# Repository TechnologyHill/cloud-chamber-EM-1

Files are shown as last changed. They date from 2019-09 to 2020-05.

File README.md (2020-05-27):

# Cloud Chamber EM-1

[more about cloud chamber](https://en.wikipedia.org/wiki/Cloud_chamber)

#### Our goal is make a small cloud chamber based on thermoelectric cooling.
#### viewport size is 100 mm x 200 mm.

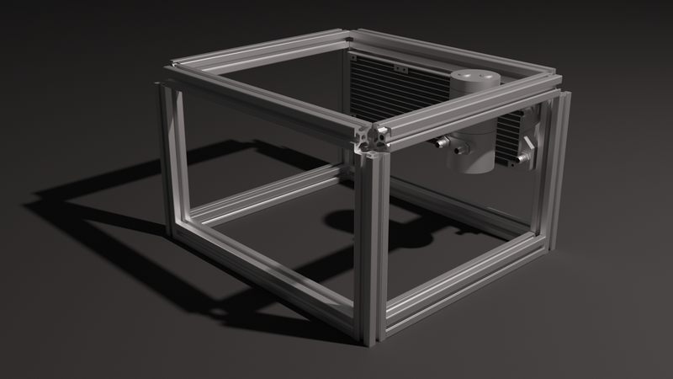
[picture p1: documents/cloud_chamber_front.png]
Cloud Chamber visualization (front)

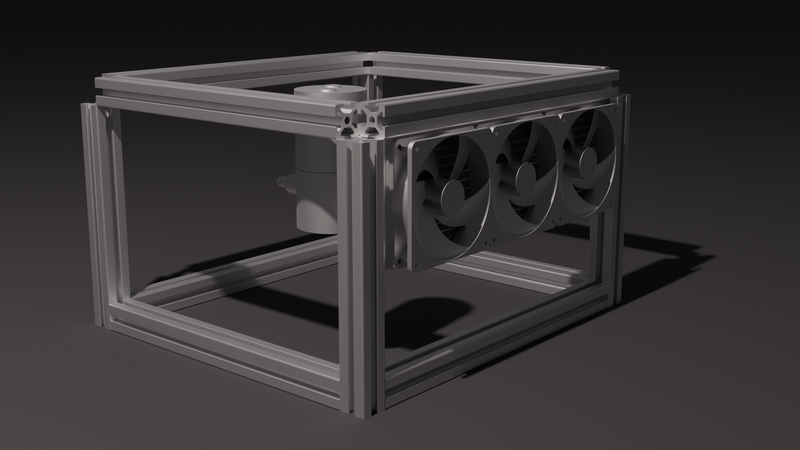
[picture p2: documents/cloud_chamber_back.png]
Cloud Chamber visualization (back)


## Cooling system
Cooling system

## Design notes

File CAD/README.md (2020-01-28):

# 3D printed models

We create 3D models in [OpenSCAD](https://www.openscad.org).

To render *.stl* files by [makefile](https://github.com/ExperimentalMakers/cloud-chamber-EM-1/blob/master/CAD/Makefile) you must install *stlsort*

```sudo pip install stlsort```

```make```

# Filename system

**1**001_P_bk.scad =>
The first digit means section of cloud chamber (casing)

1**0**01_P_bk.scad =>
The second digit means type of model (0 for *single part* or 1 for *assembly model*)

10**10**_P_bk.scad =>
The third digits means number of model

1001_**P**_bk.scad =>
The first letter means type of material (P - *PLA*, A - *ABS*, G - *PET-G*, Al, Cu, Fe)

1001_P_**bk**.scad =>
The second letters means color of material (black, white, etc.)

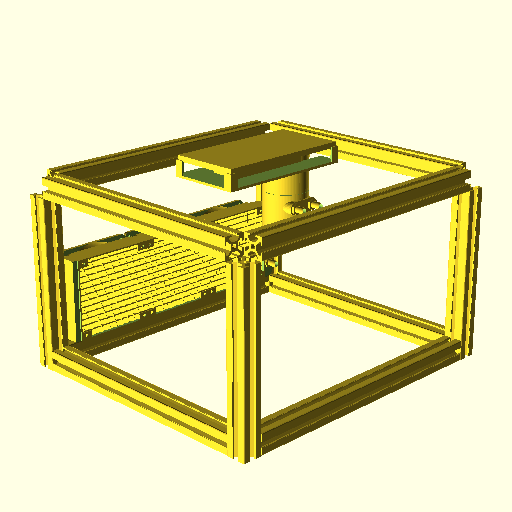
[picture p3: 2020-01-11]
CAD/images/cloud_chamber.png

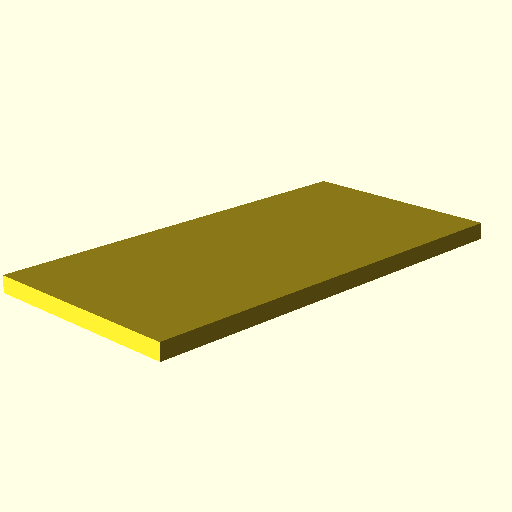
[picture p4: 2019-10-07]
CAD/images/1002_Cu.png

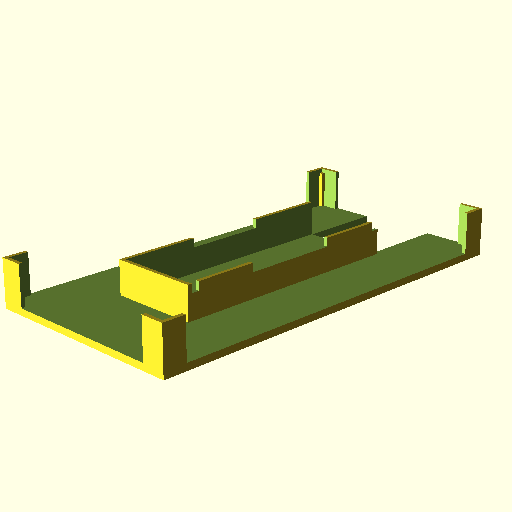
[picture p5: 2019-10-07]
CAD/images/1001_P_bk.png

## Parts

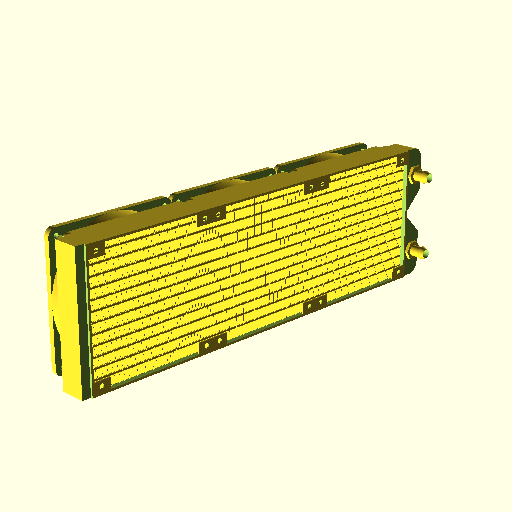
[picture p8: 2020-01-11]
CAD/images/components/fan_radiator.png

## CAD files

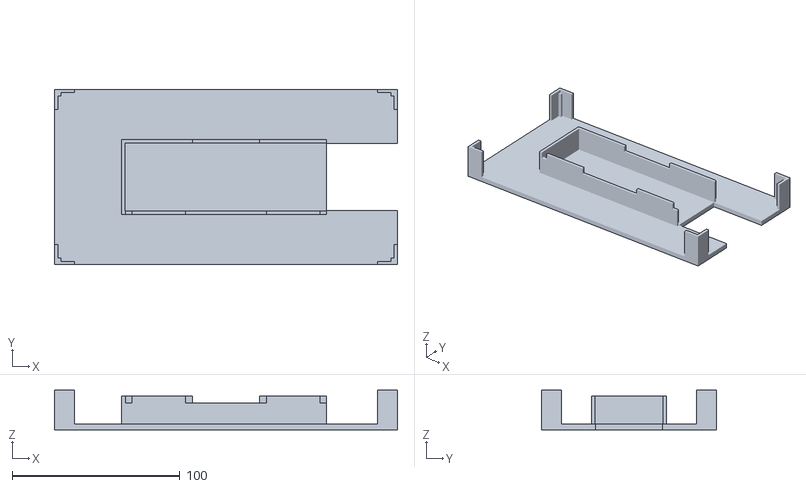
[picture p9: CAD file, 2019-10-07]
CAD/STL/1001_P_bk.stl
204.5 x 104.5 x 23.8

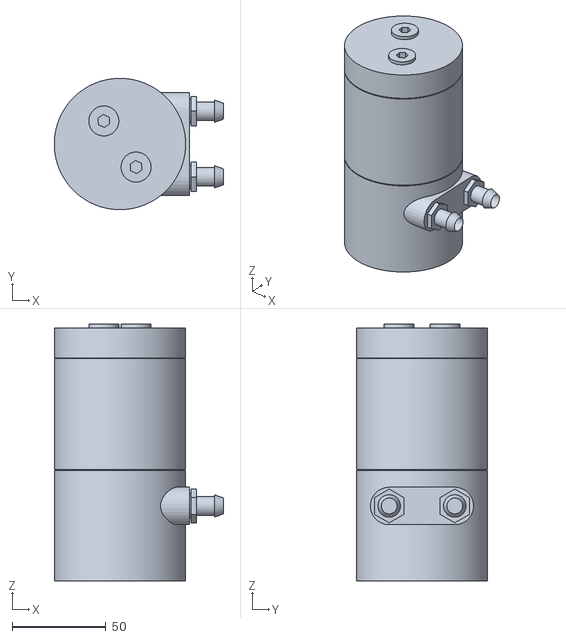
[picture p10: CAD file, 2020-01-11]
CAD/STL/components/pump.stl
90.3 x 70.0 x 137.0

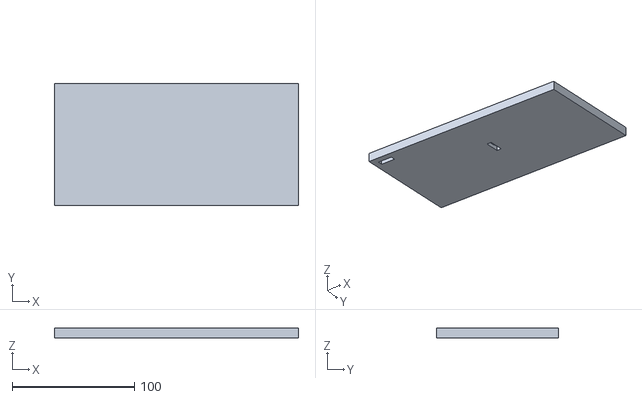
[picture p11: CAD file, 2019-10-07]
CAD/STL/1002_Cu.stl
200.0 x 100.0 x 8.00

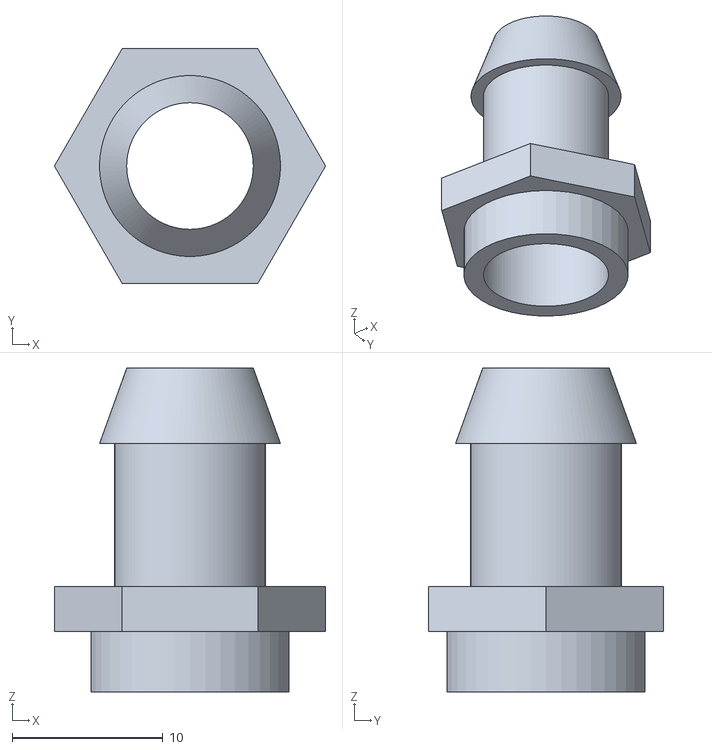
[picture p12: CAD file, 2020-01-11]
CAD/STL/components/fitting.stl
18.0 x 15.6 x 21.5

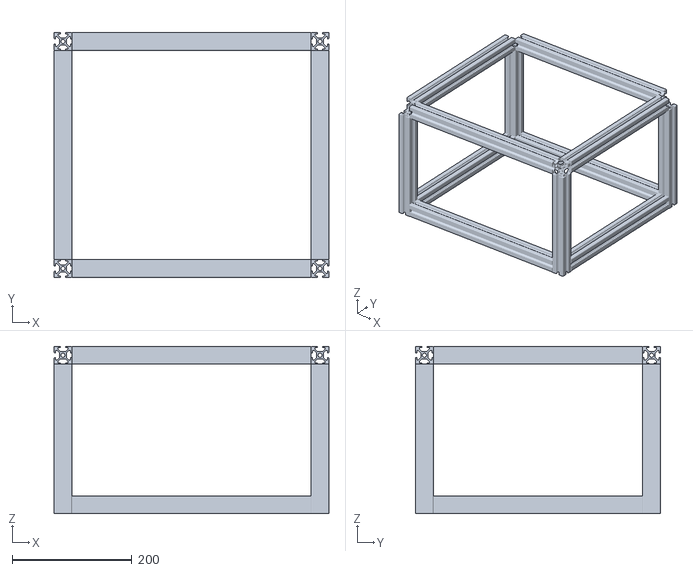
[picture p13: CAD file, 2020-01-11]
CAD/STL/components/frame.stl
460.0 x 410.0 x 280.0

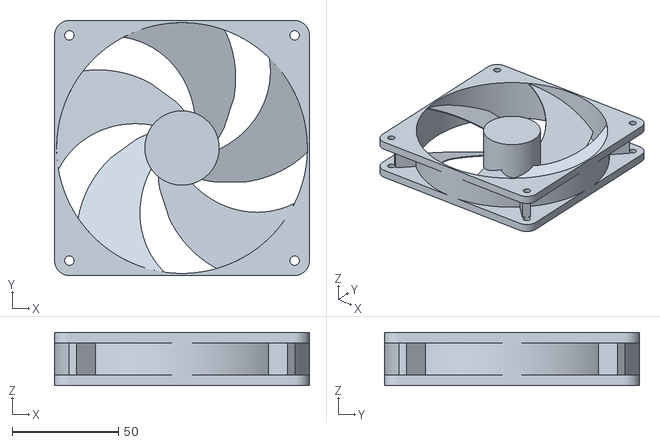
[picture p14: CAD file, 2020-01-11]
CAD/STL/components/fan.stl
120.0 x 120.0 x 25.1

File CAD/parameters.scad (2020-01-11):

//|==========================================|//
//|               CLOUD CHAMBER              |//
//|==========================================|//


//========== FUNCTIONS ==========//

//unit conversions
function inch_to_mm(inch) = inch*25.4;
function mm_to_inch(mm) = mm/25.4;


//========== SCREWS ==========//

//Screw diameter and nut for M10 [mm]
M10_screw_diameter=10.4;
M10_head_height = 10;
M10_head_diameter = 16+0.5;
M10_nut_height = 10.5;
M10_nut_diameter = 25.5;
M10_nut_pocket = 22.3;

//Screw diameter and nut for M8 [mm]
M8_screw_diameter = 8 + 1;
M8_head_height = 8;
M8_head_diameter = 13.5;
M8_nut_height = 7.5;
M8_nut_diameter = 14.4 + 0.5;
M8_nut_pocket = 13 + 0.5;

//Screw diameter and nut for M6 [mm]
M6_screw_diameter=6.5;
M6_head_diameter = 10+0.5;
M6_head_height = 6;
M6_nut_height = 4.9;
M6_nut_diameter = 11.8;
M6_nut_pocket = 10.4;

//Screw diameter and nut for M5 [mm]
M5_screw_diameter=5.5;
M5_head_height = 5;
M5_head_diameter = 13+0.5;
M5_nut_height = 4.5;
M5_nut_diameter = 9.4;
M5_nut_pocket = 8.4;

//Screw diameter and nut for M4 [mm]
M4_screw_diameter=4.5;
M4_screw_head_height = 4;
M4_nut_height = 3.2;
M4_nut_diameter = 8.4;
M4_nut_pocket = 7.5;

//Screw diameter and nut for M3 [mm]
M3_screw_diameter = 3.2;
M3_nut_height = 2.7;
M3_nut_diameter = 6.6;
M3_screw_head_height = 3;
M3_nut_pocket = 5.6;

//Screw diameter and nut for M2,5 [mm]
M2_5_screw_diameter = 2.7;
M2_5_nut_height = 2.3;
M2_5_nut_diameter = 6;
M2_5_nut_pocket = 5.1;


//========== CHAMBER ==========//

//observation_surface_x
observation_surface_x = 200.5;
observation_surface_y = 100.5;

//cooper block
cooper_block_x = 200;
cooper_block_y = 100;
cooper_block_thickness = 8;

//chamber frame
chamber_width = 400;
chamber_deepth = 350;
chamber_height = 250;

//service door
door_width = 200;

//peltiers
peltier_size_x = 40;
peltier_size_y = 40;
peltier_thickness = 2.9;
peltier_cable_diameter = 4;


//========== ALU PROFILES ==========//

//30x30 profile
ALU30_size = 30;
ALU30_groove = 8;

//20x20 profile
ALU20_size = 20;
ALU20_groove = 6;


//========== ELECTRONIC DEVICE ==========//

//TO-92 package
TO92_width = 4.6;
TO92_height = 4.6;
TO92_thickness = 3.9;
TO92_pins = 14.5;
TO92_bottom_to_pins = 1;

//nextion display 2.8"
nextion_board_width = 85;
nextion_board_height = 50;
nextion_board_thickness = 1.6;
nextion_display_width = 69.5;
nextion_display_height = 50;
nextion_thickness = 7;
nextion_screw_diameter = M2_5_screw_diameter;
nextion_screw_width_distance = 78.5;
nextion_screw_height_distance = 49;


//========== COOLING CIRCUIT ==========//

//water ALU block
water_block_width = 40;
water_block_length = 120;
water_block_thickness = 12.5;

//hose
hose_outer_diameter = 10;
hose_inner_diameter = 8;

//fitting
fitting_thread_diameter = 13.157;
fitting_thread_height = 4;
fitting_height = 14.5;
fitting_inner_diameter = 8.4;
fitting_bottom_inner_diameter = 10;
fitting_bottom_inner_height = 6;
fitting_wall_thickness = 0.8;
fitting_overhang_height = 5;
fitting_overhang_size = 1;
fitting_nut_diameter = 18;
fitting_nut_height = 3;
fitting_seal_thickness = 0.8;

//pump
pump_diameter = 70;
pump_height = 135;
pump_in_out_distance = 35;
pump_in_out_diameter = 20;
pump_in_out_height = 40;
pump_in_out_overlap = 2;
pump_cap_diameter = 16;
pump_cap_height = 2;
pump_cap_distance = 30;
pump_cap_inbus_diameter = 7;
pump_cap_inbus_height = 5;
pump_cap_angle = 35;
pump_tank_height = 60;
pump_tank_top_distance = 16;
pump_tank_furrow_height = 0.5;
pump_tank_furrow_deepth = 2;

//fan
fan_size = 120;
fan_thickness = 25;
fan_frame_thickness = 5;
fan_diameter = fan_size-2;
fan_center_diameter = 35;
fan_blade_count = 5;
fan_blade_center_size = 5;
fan_blade_outer_size = 45;
fan_blade_angle = 23;
fan_blade_thickness = 0.4;
fan_screw_diameter = M4_screw_diameter;
fan_screw_distance = 7;
fan_rotation = false;

//radiator
radiator_width = 392;
radiator_height = 120;
radiator_thickness = 27;
radiator_fpi = 16;
radiator_fin_thickness = 0.05;
radiator_frame_thickness = 2;
radiator_frame_overhang = 4;
radiator_frame_radius = 10;
radiator_fans_translate = 17-fan_screw_distance;
radiator_pipe_count = 12;
radiator_pipe_thickness = 2;
radiator_mount_height = 12;
radiator_mount_width = 31;
radiator_mount_thickness = 1;


//========== MODELS ==========//

//1001_P_bk
1001_P_bk_bottom_thickness = 3.5;

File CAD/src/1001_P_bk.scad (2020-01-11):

include <../parameters.scad>

bottom_thickness = 1001_P_bk_bottom_thickness;
border_thickness = 2;
border_height = water_block_thickness+peltier_thickness*2+2;
border_corner_size = 10;
copper_plate_support = 2;
water_block_tolerance = 0.5;

module 1001_P_bk(peltiers=false) {
    if(peltiers==true) {
        translate([0, 0, bottom_thickness+water_block_thickness/2])
            #cube([water_block_length, water_block_width, water_block_thickness], center=true);

        translate([-water_block_length/2+peltier_size_x/2, 0, bottom_thickness+water_block_thickness+peltier_thickness])
            #cube([peltier_size_x, peltier_size_y, peltier_thickness*2], center=true);

        translate([water_block_length/2-peltier_size_x/2, 0, bottom_thickness+water_block_thickness+peltier_thickness])
            #cube([peltier_size_x, peltier_size_y, peltier_thickness*2], center=true);
    }

    translate([observation_surface_x/2-copper_plate_support, observation_surface_y/2-copper_plate_support, bottom_thickness])
        cube([copper_plate_support, copper_plate_support, water_block_thickness+peltier_thickness*2]);

    translate([observation_surface_x/2-copper_plate_support, -observation_surface_y/2, bottom_thickness])
        cube([copper_plate_support, copper_plate_support, water_block_thickness+peltier_thickness*2]);

    translate([-observation_surface_x/2, observation_surface_y/2-copper_plate_support, bottom_thickness])
        cube([copper_plate_support, copper_plate_support, water_block_thickness+peltier_thickness*2]);

    translate([-observation_surface_x/2, -observation_surface_y/2, bottom_thickness])
        cube([copper_plate_support, copper_plate_support, water_block_thickness+peltier_thickness*2]);

    difference() {
        translate([0, 0, bottom_thickness+(water_block_thickness+peltier_thickness*1.5)/2]) {
            cube([water_block_length+border_thickness*2+water_block_tolerance, water_block_width+border_thickness*2+water_block_tolerance, water_block_thickness+peltier_thickness*1.5], center=true);
        }

        translate([water_block_length/2, -water_block_width, 0])
            cube([100, water_block_width*2, 100]);

        translate([0, 0 ,bottom_thickness+50])
            cube([water_block_length+water_block_tolerance, water_block_width+water_block_tolerance, 100], center=true);

        translate([-water_block_length/2, -water_block_width/2-water_block_tolerance/2-border_thickness-0.1, bottom_thickness+water_block_thickness])
            cube([peltier_cable_diameter, border_thickness*2, 20]);

        translate([-water_block_length/2+peltier_size_x-peltier_cable_diameter, -water_block_width/2-water_block_tolerance/2-border_thickness-0.1, bottom_thickness+water_block_thickness])
            cube([peltier_cable_diameter, border_thickness*2, 20]);

        translate([water_block_length/2-peltier_size_x, -water_block_width/2-water_block_tolerance/2-border_thickness-0.1, bottom_thickness+water_block_thickness])
            cube([peltier_cable_diameter, border_thickness*2, 20]);

        translate([water_block_length/2-peltier_cable_diameter, -water_block_width/2-water_block_tolerance/2-border_thickness-0.1, bottom_thickness+water_block_thickness])
            cube([peltier_cable_diameter, border_thickness*2, 20]);

        translate([0, 0, 50+bottom_thickness+water_block_thickness])
            cube([water_block_length/3+0.1, water_block_width*2, 100], center=true);
    }

    difference() {
        union() {
            translate([0, 0, (bottom_thickness+border_height)/2])
                cube([observation_surface_x+border_thickness*2, observation_surface_y+border_thickness*2, bottom_thickness+border_height], center=true);

            
        }

        translate([0, 0, bottom_thickness+50])
            cube([observation_surface_x, observation_surface_y, 100], center=true);

        translate([0, 0, bottom_thickness+50])
            cube([observation_surface_x-border_corner_size*2, observation_surface_y*2, 100], center=true);

        translate([0, 0, bottom_thickness+50])
            cube([observation_surface_x*2, observation_surface_y-border_corner_size*2, 100], center=true);

        translate([water_block_length/2+observation_surface_x/2, 0, 0])
            cube([observation_surface_x, water_block_width, bottom_thickness*3], center=true);
    }
}

1001_P_bk();

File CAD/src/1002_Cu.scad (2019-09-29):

include <../parameters.scad>

module 1002_Cu() {

    module TO92() {
        translate([0, 0, TO92_thickness/2-0.1])
            cube([TO92_width, TO92_height, TO92_thickness+0.1], center=true);

        translate([0, (TO92_pins-5)/-2-TO92_height/2+0.1, (TO92_thickness-TO92_bottom_to_pins)/2-0.1+0.25])
            cube([TO92_width, TO92_pins-5, TO92_thickness-TO92_bottom_to_pins+0.1+0.5], center=true);
    }

    difference() {
        translate([0, 0, cooper_block_thickness/2]) {
            cube([cooper_block_x, cooper_block_y, cooper_block_thickness], center=true);
        }

        TO92();

        translate([-cooper_block_x/2+8, -cooper_block_y/2+8, 0])
            rotate([0, 0, 90])
                TO92();   
    }
}

1002_Cu();

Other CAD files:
CAD/src/cloud_chamber.scad
CAD/src/components/fan.scad
CAD/src/components/fan_radiator.scad
CAD/src/components/fitting.scad
CAD/src/components/frame.scad
CAD/src/components/pump.scad
CAD/src/components/radiator.scad

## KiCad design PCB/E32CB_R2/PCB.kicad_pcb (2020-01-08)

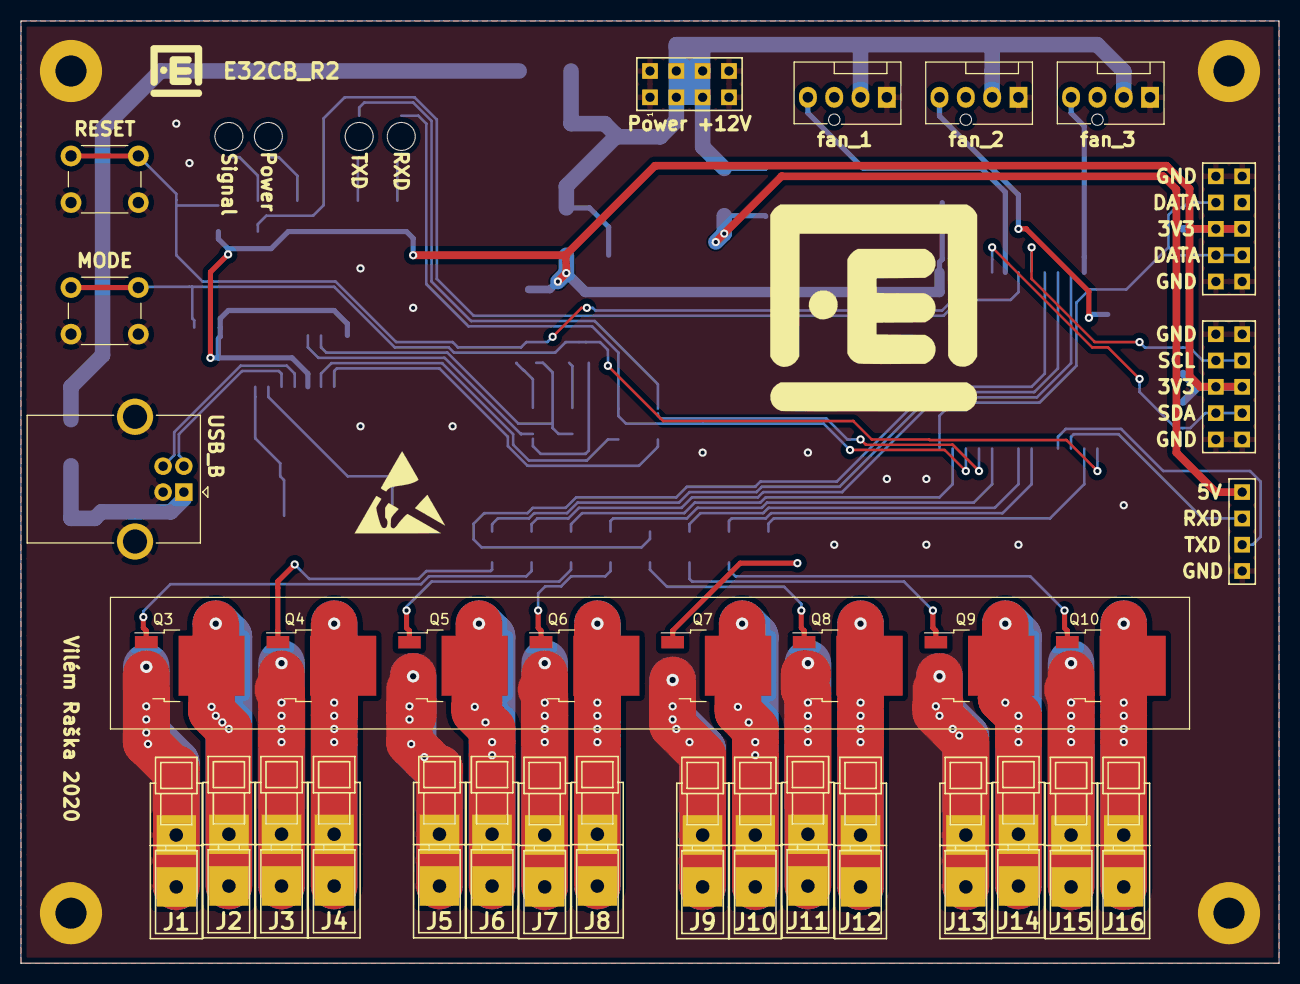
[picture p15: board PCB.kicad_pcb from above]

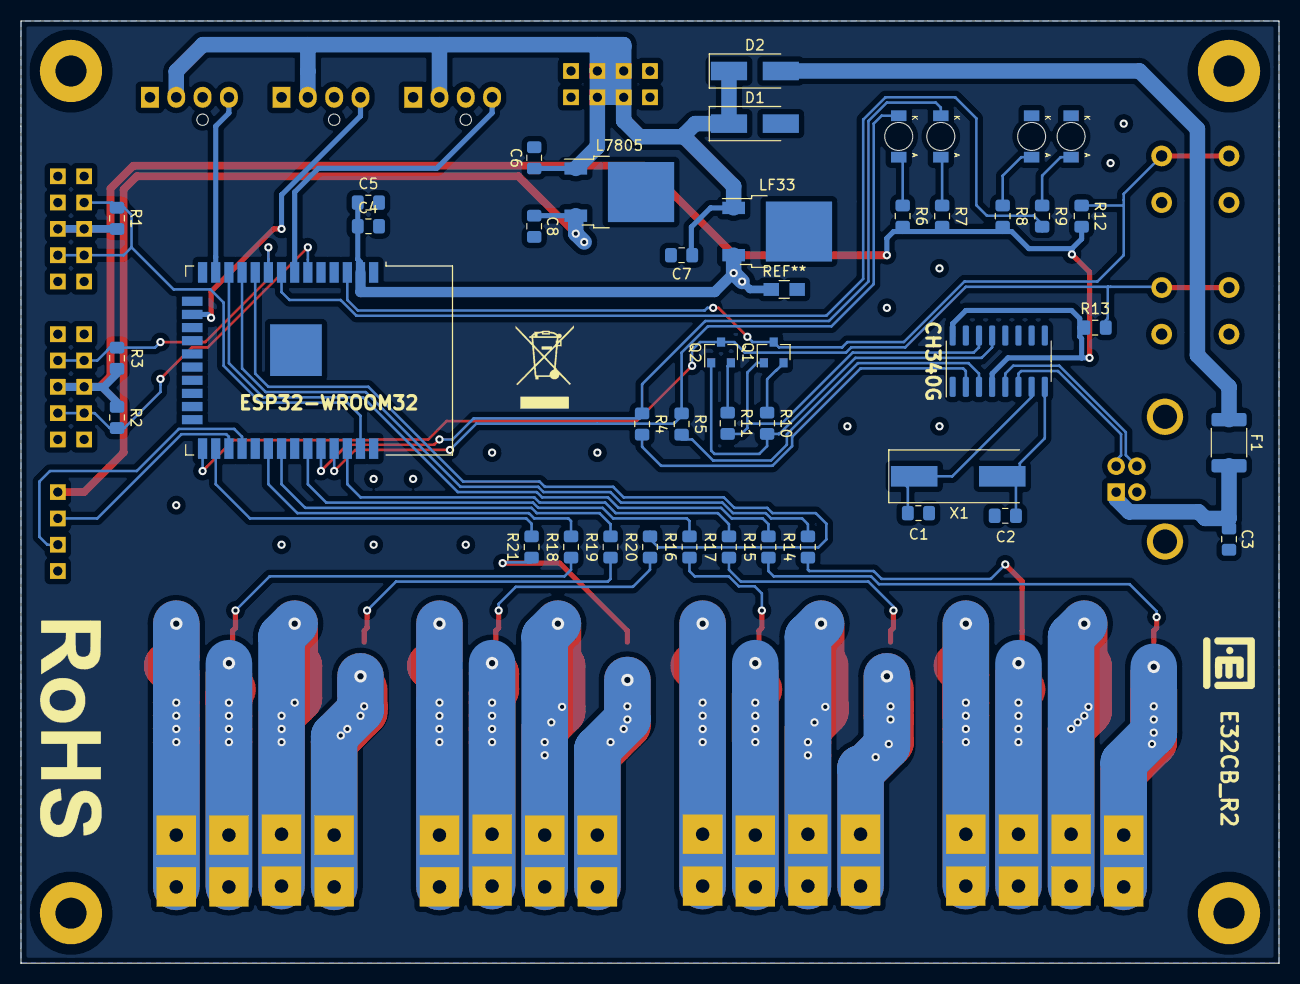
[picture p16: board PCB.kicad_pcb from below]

Board: 2 copper layers, 121.4 x 90.9 mm, 81 parts (43 on the bottom side), 57 nets.

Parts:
C1, C2: 22p; C_0805_2012Metric_Pad1.15x1.40mm_HandSolder
C3: 10nF; C_0805_2012Metric_Pad1.15x1.40mm_HandSolder
C4, C7, C8: 100nF; C_0805_2012Metric_Pad1.15x1.40mm_HandSolder
C5: 10uF; C_0805_2012Metric_Pad1.15x1.40mm_HandSolder
C6: 330nF; C_0805_2012Metric_Pad1.15x1.40mm_HandSolder
CH340G: CH340G; SOIC-16_3.9x9.9mm_P1.27mm
D1, D2: 1N4007; D_SMA_Handsoldering
ESP32-WROOM32: ESP32-WROOM-32
F1: 1A; Fuse_1812_4532Metric_Pad1.30x3.40mm_HandSolder
H1, H2, H3, H4: M3; MountingHole_3mm
J1, J3, J5, J7, J9, J11, J13, J15: GND; WAGO256
J2: pump; WAGO256
J4: LED; WAGO256
J6: P12B; WAGO256
J8: P12A; WAGO256
J10: VM1; WAGO256
J12: VM2; WAGO256
J14: P3B; WAGO256
J16: P3A; WAGO256
J17: NEXTION; Straight_1x04
J18: Power; Straight_2x04
J19: OneWire; Straight_2x05
J20: I2C; Straight_2x05
L7805: 5Vstabilizer; TO-252-2
LF33: 3V3stabilizer; TO-252-2
MODE: SW_Push; SW_PUSH_6mm_h4.3mm
Power: LED_R; LED_1206
Q1, Q2: S8050; SOT-23
Q3, Q4, Q5, Q6, Q7, Q8, Q9, Q10: IRLR2905; TO-252-2
R1: 4k7; R_0805_2012Metric_Pad1.15x1.40mm_HandSolder
R2, R3: 1k2; R_0805_2012Metric_Pad1.15x1.40mm_HandSolder
R4, R5, R14, R15, R16, R17, R18, R19, R20, R21: 470R; R_0805_2012Metric_Pad1.15x1.40mm_HandSolder
R6, R7, R8, R9: 1k; R_0805_2012Metric_Pad1.15x1.40mm_HandSolder
R10, R11: 12k; R_0805_2012Metric_Pad1.15x1.40mm_HandSolder
R12, R13: 10k; R_0805_2012Metric_Pad1.15x1.40mm_HandSolder
RESET: SW_Push; SW_PUSH_6mm_h4.3mm
RXD: LED_R; LED_1206
Signal: LED_R; LED_1206
TXD: LED_R; LED_1206
USB_B: USB_B; USB_B_OST_USB-B1HSxx_Horizontal
X1: 12MHz; Crystal_SMD_HC49-SD
fan_1, fan_2, fan_3: Conn_01x04; FanPinHeader_1x04_P2.54mm_Vertical

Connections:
+3V3: C4.1, C5.1, CH340G.4, CH340G.16, ESP32-WROOM32.2, J19.5, J19.6, J20.5, J20.6, LF33.3, R1.2, R2.1, R3.1, R6.2, R7.2, R8.2, R12.1, R13.1
+5V: D2.2, F1.1
+12V: C6.1, C7.1, D1.1, D2.1, J18.3, J18.4, J18.5, J18.6, L7805.1, LF33.1, fan_1.2, fan_2.2, fan_3.2
/EN: ESP32-WROOM32.3, Q1.3, R12.2, RESET.1
/I2C_SCL: ESP32-WROOM32.9, J20.7, J20.8, R3.2
/I2C_SDA: ESP32-WROOM32.6, J20.3, J20.4, R2.2
/IO_0: ESP32-WROOM32.25, MODE.1, Q2.3, R13.2
/LED: ESP32-WROOM32.11, R14.2
/OneWire: ESP32-WROOM32.37, J19.3, J19.4, J19.7, J19.8, R1.1
/P3A: ESP32-WROOM32.30, R18.2
/P3B: ESP32-WROOM32.31, R19.2
/P12A: ESP32-WROOM32.33, R16.2
/P12B: ESP32-WROOM32.36, R17.2
/RXD: ESP32-WROOM32.35, R5.1, RXD.1
/TXD: ESP32-WROOM32.34, R4.1, TXD.1
/U2_RXD: ESP32-WROOM32.27, J17.3
/U2_TXD: ESP32-WROOM32.28, J17.2
/USB_N: CH340G.6, USB_B.2
/USB_P: CH340G.5, USB_B.3
/VM1: ESP32-WROOM32.26, R21.2
/VM2: ESP32-WROOM32.10, R20.2
/display_Vin: C8.1, J17.4, L7805.3
/fan1: ESP32-WROOM32.7, fan_1.4
/fan2: ESP32-WROOM32.16, fan_2.4
/fan3: ESP32-WROOM32.13, fan_3.4
/pump: ESP32-WROOM32.12, R15.2
/s_LED: ESP32-WROOM32.8, R9.2
GND: C1.2, C2.2, C3.2, C4.2, C5.2, C6.2, C7.2, C8.2, CH340G.1, D1.2, ESP32-WROOM32.1, ESP32-WROOM32.15, ESP32-WROOM32.38, H1.1, H2.1, H3.1, H4.1, J1.1, J3.1, J5.1, J7.1, J9.1, J11.1, J13.1, J15.1, J17.1, J18.1, J18.2, J18.7, J18.8, J19.1, J19.2, J19.9, J19.10, J20.1, J20.2, J20.9, J20.10, L7805.2, LF33.2, MODE.2, Power.1, Q3.3, Q4.3, Q5.3, Q6.3, Q7.3, Q8.3, Q9.3, Q10.3, RESET.2, Signal.1, USB_B.4, USB_B.5, fan_1.1, fan_2.1, fan_3.1
unnamed: C1.1, CH340G.7, X1.1
unnamed: C2.1, CH340G.8, X1.2
unnamed: C3.1, F1.2, USB_B.1
unnamed: CH340G.2, R4.2
unnamed: CH340G.3, R5.2
unnamed: CH340G.13, Q2.1, R10.2
unnamed: CH340G.14, Q1.1, R11.2
unnamed: J2.1, Q3.2
unnamed: J4.1, Q4.2
unnamed: J6.1, Q5.2
unnamed: J8.1, Q6.2
unnamed: J10.1, Q7.2
unnamed: J12.1, Q8.2
unnamed: J14.1, Q9.2
unnamed: J16.1, Q10.2
unnamed: Power.2, R8.1
unnamed: Q1.2, R10.1
unnamed: Q2.2, R11.1
unnamed: Q3.1, R15.1
unnamed: Q4.1, R14.1
unnamed: Q5.1, R17.1
unnamed: Q6.1, R16.1
unnamed: Q7.1, R21.1
unnamed: Q8.1, R20.1
unnamed: Q9.1, R19.1
unnamed: Q10.1, R18.1
unnamed: R6.1, RXD.2
unnamed: R7.1, TXD.2
unnamed: R9.1, Signal.2

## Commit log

2019-06-12 screws parameters
    [parameters.scad]
2019-08-12 makefile, parameters and readme
    [parameters.scad]
2019-08-28 footprint update
    [PCB.sch]
2019-08-29 1001_AB.scad added
    [1001_AB.scad, 1001_AB.stl]
2019-08-30 uprava PCB
    [PCB.sch]
2019-08-30 1001_AB update
    [1001_AB.scad, parameters.scad]
2019-08-30 rendering models
    [1001_AB.stl]
2019-08-30 1001_AB upgrade
    [1001_AB.scad, 1001_AB.stl, parameters.scad]
2019-08-31 rename 1001_Pbk
    [1001_Pbk.scad]
2019-09-03 pcb modified
    [PCB.kicad_pcb, PCB.sch]
2019-09-04 PCB update
    [PCB.sch]
2019-09-05 models rendering and 2001_Pbk
    [1001_AB.stl, 1001_Pbk.scad, 1001_Pbk.stl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]
2019-09-06 parameters update
    [parameters.scad]
2019-09-06 readme update
    [parameters.scad]
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2019-09-08 pin fix
    [PCB.sch]
2019-09-09 oprava hozměrů nextionu #3
    [parameters.scad]
2019-09-09 pcb update #4
    [PCB.sch]
2019-09-10 pdf created #4
    [PCB.sch]
2019-09-14 PCB reated #4
    [PCB.kicad_pcb, PCB.sch]
2019-09-15 gerbers created
    [PCB-B_Cu.gbr, PCB-B_Mask.gbr, PCB-B_SilkS.gbr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]
2019-09-18 PCB General UPGRADE
    [PCB-B_Cu.gbr, PCB-B_Mask.gbr, PCB-B_Paste.gbr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]
2019-09-18 PCB silkscreen update
    [PCB-B_Cu.gbr, PCB-B_Mask.gbr, PCB-B_Paste.gbr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]
2019-09-19 new alu profiles library
    [2001_Pbk.scad, 2001_Pbk.stl]
2019-09-23 chamber main frame added
    [0101.scad, 0101.stl, parameters.scad]
2019-09-23 ALU profile R - radius update
    [0101.stl]
2019-09-23 part rename
    [2101_Al.scad]
2019-09-24 frame update
    [0101.stl, 2101_Al.scad, 2101_Al.stl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]
2019-09-28 ALU profile name fixed
    [2101_Al.scad]
2019-09-29 Cu deska
    [1002_Cu.scad, parameters.scad]
2019-10-07 Cu block fixed
    [1001_Pbk.stl, 1002_Cu.stl, parameters.scad]
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2019-12-09 pcb, power and 3v3
    [PCB.sch]
2019-12-10 pwm fan #4
    [PCB.sch]
2019-12-10 pcb mounting holes #4
    [PCB.sch]
2019-12-10 PWM cooling fans #4
    [PCB.sch]
2019-12-10 I2C #4
    [PCB.sch]
2019-12-10 NEXTION connector #4
    [PCB.sch]
2019-12-10 blocks align #4
    [PCB.sch]
2019-12-10 OneWire #4
    [PCB.sch]
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2019-12-10 footprint update #4
    [PCB.sch]
2019-12-10 schema #4
    [PCB.sch]
2019-12-11 OneWire update #4
    [PCB.sch]
2019-12-11 pump added
    [parameters.scad, pump.scad, pump.stl]
2019-12-11 USB CH340G update #4
    [PCB.sch]
2019-12-11 LED indicator #4
    [PCB.sch]
2019-12-11 schema update #4
    [PCB.sch]
2019-12-16 fan & radiator
    [fan.scad, fan.stl, parameters.scad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]
2019-12-16 renderig models (fan)
    [fan.stl]
2019-12-16 radiator assembly
    [3101.scad]
2019-12-16 renderig models
    [3101.stl]
2019-12-17 3101 rendering
    [3101.stl, fan.stl, parameters.scad]
2019-12-17 unit conversions
    [3101.scad, parameters.scad, radiator.scad]
2019-12-17 fan upgrade
    [fan.scad, parameters.scad, radiator.scad]
2019-12-17 radiator and fan
    [fan.stl, fitting.stl, pump.stl]
2019-12-18 reset circuit update
    [PCB.sch]
2019-12-18 logo added #4
    [PCB.sch]
2019-12-18 mosfet added #4
    [PCB.sch]
2019-12-18 peltiers #4
    [PCB.sch]
2019-12-19 MOSFET gate R added #4
    [PCB.sch]
2019-12-19 LED + pump #4
    [PCB.sch]
2019-12-19 schema restructure #4
    [PCB.sch]
2019-12-19 mlab schematics added #4
    [PCB.sch]
2019-12-21 pcb #4
    [PCB.kicad_pcb]
2019-12-30 fitting dimensions update
    [parameters.scad]
2019-12-30 fitting dimensions upgrade
    [fitting.scad, parameters.scad]
2019-12-30 pump dimensions update
    [fitting.scad, parameters.scad, pump.scad]
2019-12-30 fan dimensions update
    [fan.scad, parameters.scad]
2019-12-30 radiator dimensions update
    [parameters.scad, radiator.scad]
2019-12-30 3101 update
    [3101.scad]
2019-12-30 rendering components
    [fan.stl, fitting.stl, pump.stl]
2019-12-30 alu frame update
    [2101_Al.scad, 2101_Al.stl]
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2020-01-04 pcb dimensions and mounting holes #4
    [PCB.kicad_pcb]
2020-01-04 components added into board #4
    [PCB.kicad_pcb]
2020-01-04 reset circuit #4
    [PCB.kicad_pcb]
2020-01-04 indication LED #4
    [PCB.kicad_pcb]
2020-01-04 pcb finish #4
    [PCB.kicad_pcb]
2020-01-05 gerber #4
    [PCB-B_Cu.gbr, PCB-B_Mask.gbr, PCB-B_Paste.gbr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]
2020-01-05 gerber regenerate
    [PCB-B_Cu.gbr, PCB-B_Mask.gbr, PCB-B_Paste.gbr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]
2020-01-06 CDA path update
    [1001_P_bk.scad]
2020-01-06 new render of cloud chamber
    [1001_P_bk.stl, 2101_Al.scad, 3101.scad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]
2020-01-06 del old files
    [1001_Pbk.stl, 2101_Al.stl]
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2020-01-07 chamber update
    [1001_P_bk.scad, cloud_chamber.scad, parameters.scad]
2020-01-07 modules position
    [cloud_chamber.scad]
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2020-01-10 gerber, powered by mlab
    [DSB_R1-B_Cu.gbr, DSB_R1-B_Mask.gbr, DSB_R1-B_Paste.gbr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]
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2020-01-13 conflict fixed
    [E32CB_R2-B_Cu.gbr, E32CB_R2-B_Mask.gbr, E32CB_R2-B_Paste.gbr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]
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2020-03-03 esp pin update, pin header added
    [E32CB_R2.sch]
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2020-04-17 reset section
    [E32CB_R2.kicad_pcb, E32CB_R2.sch]
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2020-04-18 gpio header pins changed
    [E32CB_R2.kicad_pcb, E32CB_R2.sch]
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2020-04-28 powered by mlab added
    [E32CB_R2-B.Cu.gbr, E32CB_R2-B.Mask.gbr, E32CB_R2-B.SilkS.gbr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]
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2020-07-15 wago position on PCB finished
    [E32CB_R2.kicad_pcb]
2020-07-15 all conponents placed on PCB
    [E32CB_R2.kicad_pcb]
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2020-07-16 temperature sensor fixed
    [MCPB_R1-B.Cu.gbr, MCPB_R1-B.Mask.gbr, MCPB_R1-B.SilkS.gbr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]
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2020-07-21 gerber for stencil generated
    [E32CB_R2-B.Cu.gbr, E32CB_R2-B.Mask.gbr, E32CB_R2-B.Paste.gbr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]
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2021-07-01 PCBs separated from repository
    [DSB_R1-B_Cu.gbr, DSB_R1-B_Mask.gbr, DSB_R1-B_Paste.gbr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]
